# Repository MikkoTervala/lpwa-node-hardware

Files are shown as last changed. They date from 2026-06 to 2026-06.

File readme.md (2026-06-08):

# LPWA Node Hardware

Low power LTE Cat M / NB IoT cellular network temperature and humidity logger.

## Design Overview

The design is based on a combination of the ESP32-C3 and the SIMCom SIM7080G. An ESP32 family microcontroller was chosen as it offers good compatibility with ESPHome firmware generation tools, making the board more broadly usable for home automation purposes. In its intended use, the WiFi and Bluetooth functions will not be used. The purpose of the microcontroller is to gather temperature and humidity readings and transmit them to a server over a cellular connection using the SIM7080 modem.

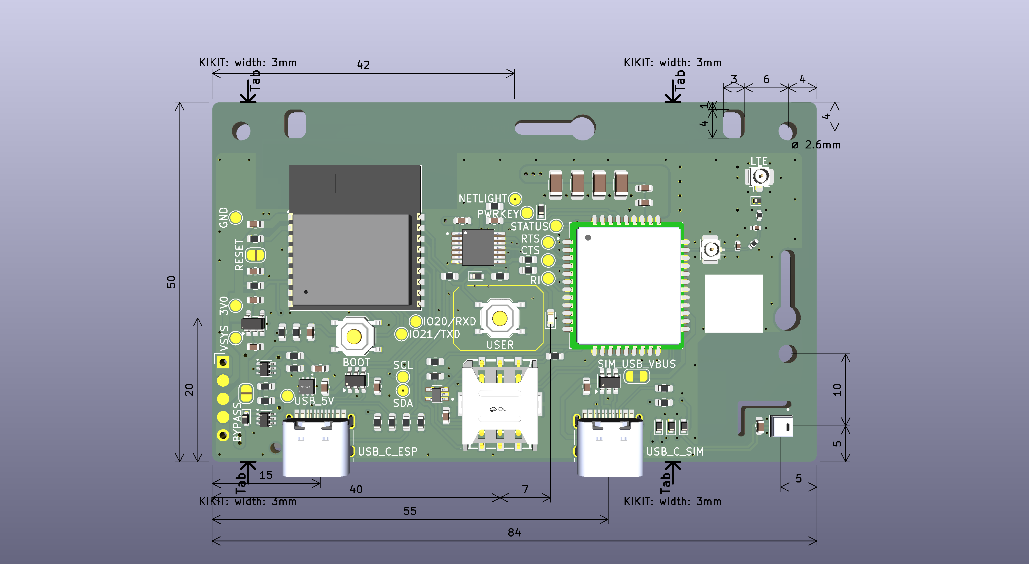
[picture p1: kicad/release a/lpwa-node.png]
LPWA Node PCB


## Views and Schematics

- [Schematic and board layout](https://kicanvas.org/?repo=https%3A%2F%2Fgithub.com%2FMikkoTervala%2Flpwa-node-hardware%2Ftree%2Fmain%2Fkicad)
- [Interactive 3D view](https://3dviewer.net/index.html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)

## Remarks

The 3.0V regulator is selected with low quiescent current as the top priority, and it cannot sustain enough current to the ESP32-C3 in WiFi operation. Replace the regulator with TLV75730PDBVR before enabling WiFi.

Maximum allowed battery voltage for the system is 4.8V. Do not use lithium 1.5V batteries as their open circuit voltage exceeds limits of this design. Stick to NiMH and alkaline.

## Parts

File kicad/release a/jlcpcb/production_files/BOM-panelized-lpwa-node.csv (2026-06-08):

Comment | Designator | Footprint | LCSC | Quantity
100k | R18,R25 | R_0603_1608Metric | C25803 | 2
100nF | C12,C14,C15,C4,C7,C8,C9 | C_0603_1608Metric | C161115 | 7
100µF | C11,C13,C22,C23 | C_1206_3216Metric | C7432784 | 4
10k | R1,R2,R21,R22,R3 | R_0603_1608Metric | C25804 | 5
10µF | C1,C10,C2,C20,C21,C3,C5,C6 | C_0603_1608Metric | C19702 | 8
1M | R20,R23,R8,R9 | R_0603_1608Metric | C22935 | 4
22R | R10,R11,R12 | R_0603_1608Metric | C23345 | 3
5.1k | R13,R14,R4,R5,R6,R7 | R_0603_1608Metric | C23186 | 6
732k | R19,R24 | R_0603_1608Metric | C23239 | 2
AHT20 | U4 | AHT20 | C3012622 | 1
BH-AA-B6AA044 | U5 | BAT-SMD_BH-AA-B6AA044 | C19184082 | 1
BOOT | SW1 | SW_Push_1P1T_XKB_TS-1187A | C480267 | 1
ESD5Z3.3T1G | D2,D4,D7,D8,D9 | D_SOD-523 | C61148 | 5
ESD5Z5.0T1G | D3 | D_SOD-523 | C82044 | 1
ESDA6V1W5 | D5 | SOT65P210X110-5N | C48677 | 1
ESP32-C3-WROOM-02 | U3 | ESP32-C3-WROOM-02 | C2934560 | 1
LED Amber BL-HJC36G-AV-TRB | D1 | LED_0603_1608Metric | C165983 | 1
LM66100DCK | U10,U11 | SOT-363_SC-70-6 | C2869734 | 2
LTE | J8 | U.FL_Hirose_U.FL-R-SMT-1_Vertical | C88374 | 1
LXES15AAA1-153 | D6 | D_SOD-882 | C7472903 | 1
R0 | R15,R16 | R_0402_1005Metric | C60485 | 2
SIM7080G | U6 | SIM7080G | C18548266 | 1
SIM_Card | J5 | SMN-304 | C266889 | 1
TLV75901PDRVR | U9 | WSON-6_L2.0-W2.0-P0.65-TL-EP | C544759 | 1
TPS7A0230PDBVR | U1 | SOT-23-5 | C3747031 | 1
TXU0204PWR | U7 | SOP65P640X120-14N | C4363888 | 1
USBLC6-2SC6 | U2,U8 | SOT-23-6 | C7519 | 2
USB_C_ESP | J1 | USB_C_Receptacle_HRO_TYPE-C-31-M-12 | C165948 | 1
USER | SW2 | SW_Push_1P1T_XKB_TS-1187A | C480267 | 1

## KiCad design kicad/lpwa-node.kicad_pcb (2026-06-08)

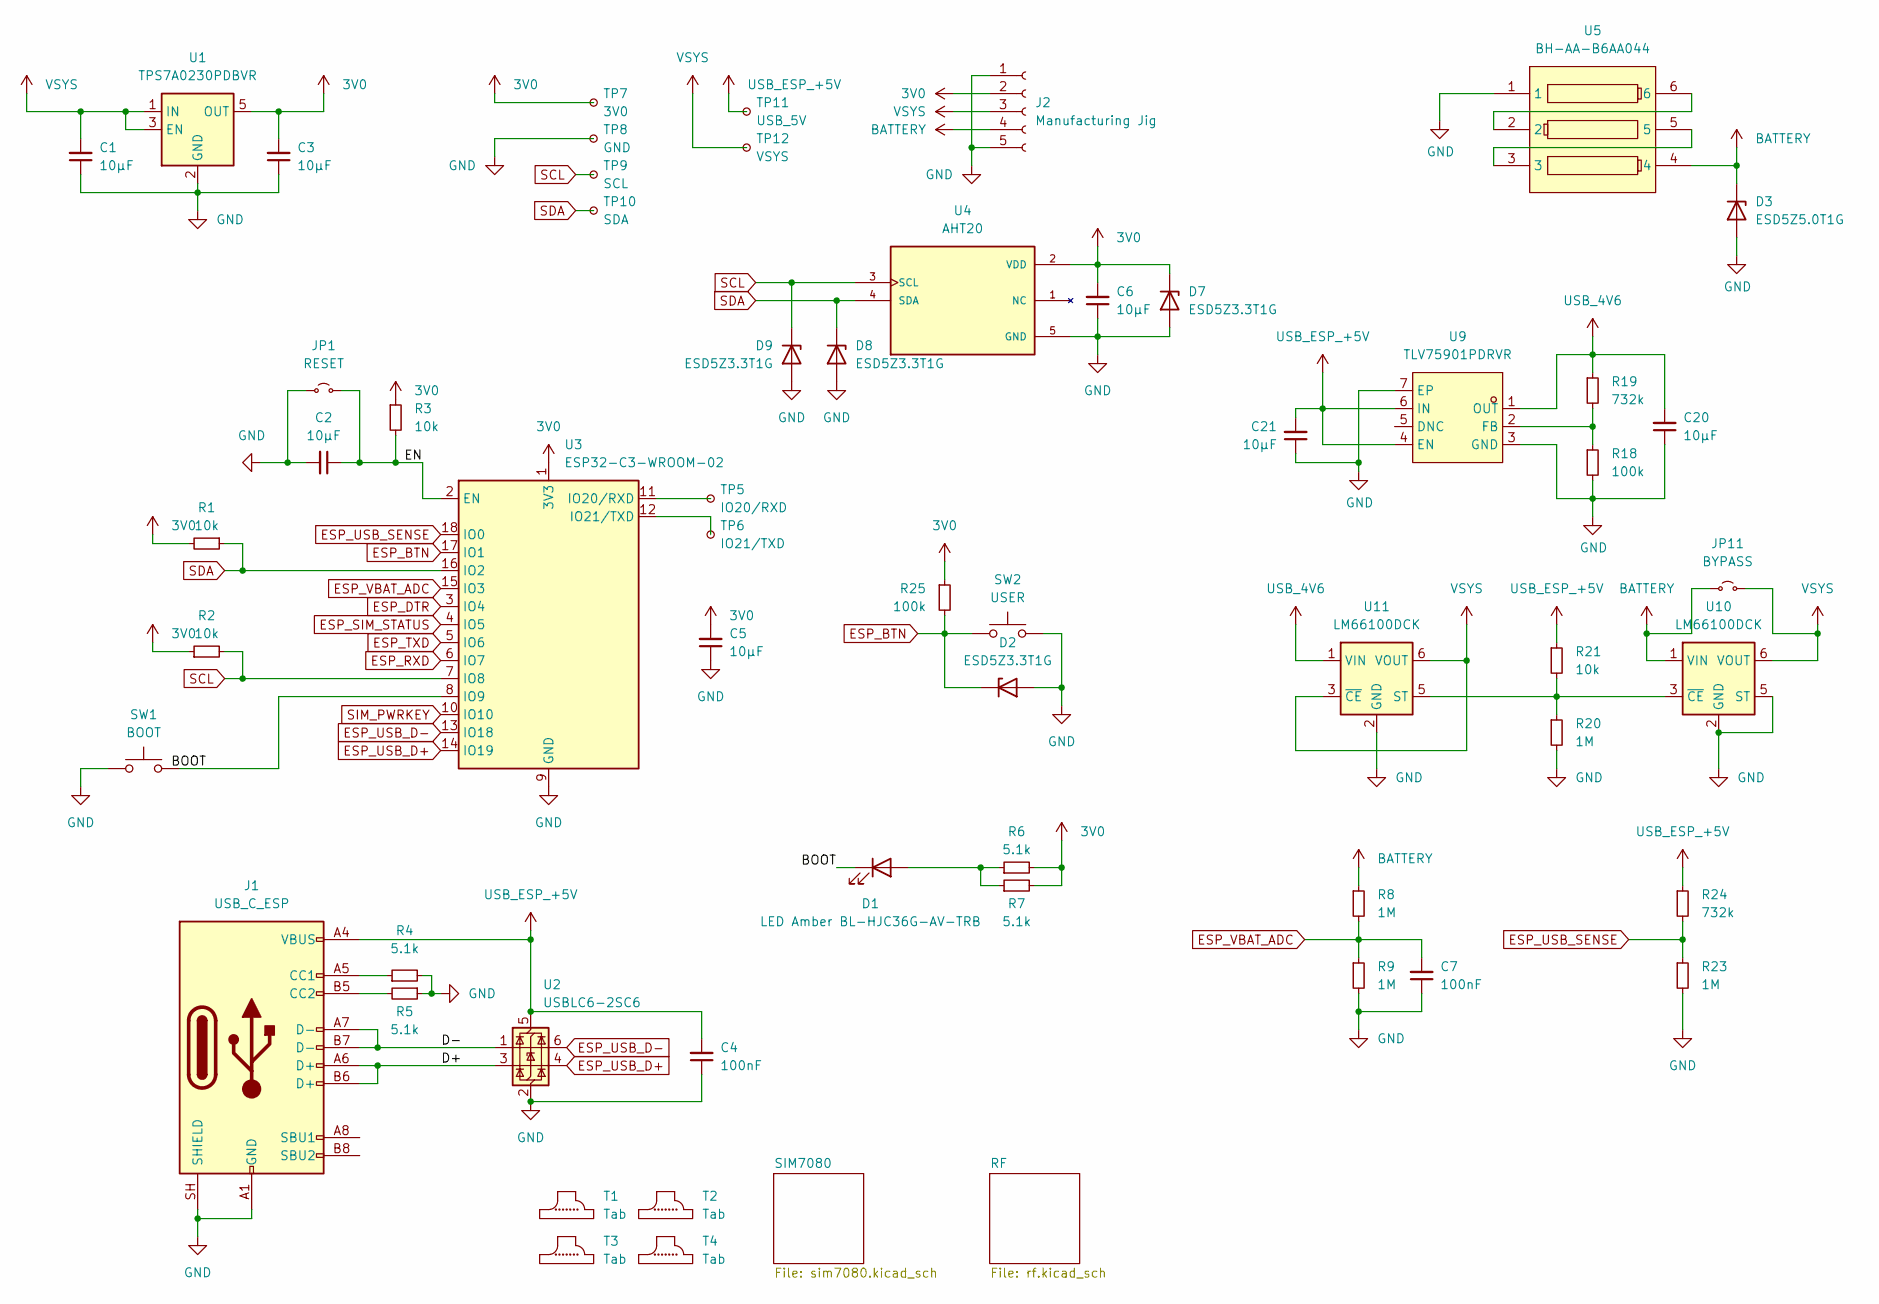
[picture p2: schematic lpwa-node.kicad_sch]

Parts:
C1, C2, C3, C5, C6, C20, C21: 10µF; C_0603_1608Metric; LCSC Part # C19702
C4, C7: 100nF; C_0603_1608Metric; LCSC Part # C161115
D1: LED Amber BL-HJC36G-AV-TRB; LED_0603_1608Metric; LCSC Part # C165983
D2, D7, D8, D9: ESD5Z3.3T1G; D_SOD-523; LCSC Part # C61148
D3: ESD5Z5.0T1G; D_SOD-523; LCSC Part # C82044
J1: USB_C_ESP; USB_C_Receptacle_HRO_TYPE-C-31-M-12; LCSC Part # C165948
J2: Manufacturing Jig; TestHeader_1x05_P2.54mm
JP1: RESET; SolderJumper-2_P1.3mm_Open_RoundedPad1.0x1.5mm
JP11: BYPASS; SolderJumper-2_P1.3mm_Open_RoundedPad1.0x1.5mm
R1, R2, R3, R21: 10k; R_0603_1608Metric; LCSC Part # C25804
R4, R5, R6, R7: 5.1k; R_0603_1608Metric; LCSC Part # C23186
R8, R9, R20, R23: 1M; R_0603_1608Metric; LCSC Part # C22935
R18, R25: 100k; R_0603_1608Metric; LCSC Part # C25803
R19, R24: 732k; R_0603_1608Metric; LCSC Part # C23239
SW1: BOOT; SW_Push_1P1T_XKB_TS-1187A; LCSC Part # C480267
SW2: USER; SW_Push_1P1T_XKB_TS-1187A; LCSC Part # C480267
T1, T2, T3, T4: Tab
TP5: IO20/RXD; TestPoint_Pad_D1.5mm
TP6: IO21/TXD; TestPoint_Pad_D1.5mm
TP7: 3V0; TestPoint_Pad_D1.5mm
TP8: GND; TestPoint_Pad_D1.5mm
TP9: SCL; TestPoint_Pad_D1.5mm
TP10: SDA; TestPoint_Pad_D1.5mm
TP11: USB_5V; TestPoint_Pad_D1.5mm
TP12: VSYS; TestPoint_Pad_D1.5mm
U1: TPS7A0230PDBVR; SOT-23-5; LCSC Part # C3747031
U2: USBLC6-2SC6; SOT-23-6; LCSC Part # C7519
U3: ESP32-C3-WROOM-02; LCSC Part # C2934560
U4: AHT20; PARTREV V1.0; LCSC Part # C3012622
U5: BH-AA-B6AA044; BAT-SMD_BH-AA-B6AA044; MPN BH-AA-B6AA044; LCSC Part # C19184082
U9: TLV75901PDRVR; WSON-6_L2.0-W2.0-P0.65-TL-EP; MPN TLV75901PDRVR; LCSC Part # C544759
U10, U11: LM66100DCK; SOT-363_SC-70-6; LCSC Part # C2869734

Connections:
3V0: C3.2, C5.2, C6.2, D7.1 (K), J2.2, R1.2, R2.1, R3.1, R6.2, R7.2, R25.1, TP7.1 (1_1), U1.5 (OUT), U3.1 (3V3), U4.2 (VDD); also elsewhere on the board
/BOOT: D1.1 (K), SW1.2, U3.8 (IO9)
/D+: J1.A6 (D+), J1.B6 (D+), U2.3 (I/O2)
/D-: J1.A7 (D-), J1.B7 (D-), U2.1 (I/O1)
/EN: C2.1, JP1.2 (B), R3.2, U3.2 (EN)
BATTERY: D3.1 (K), J2.4, JP11.1 (A), R8.1, U5.4, U10.1 (VIN)
ESP_BTN: D2.1 (K), R25.2, SW2.1, U3.17 (IO1)
ESP_DTR: U3.3 (IO4); also elsewhere on the board
ESP_RXD: U3.6 (IO7); also elsewhere on the board
ESP_SIM_STATUS: U3.4 (IO5); also elsewhere on the board
ESP_TXD: U3.5 (IO6); also elsewhere on the board
ESP_USB_D+: U2.4 (I/O2), U3.14 (IO19)
ESP_USB_D-: U2.6 (I/O1), U3.13 (IO18)
ESP_USB_SENSE: R23.1, R24.2, U3.18 (IO0)
ESP_VBAT_ADC: C7.2, R8.2, R9.1, U3.15 (IO3)
GND: C1.1, C2.2, C3.1, C4.1, C5.1, C6.1, C7.1, C20.1, C21.1, D2.2 (A), D3.2 (A), D7.2 (A), D8.2 (A), D9.2 (A), J1.A1 (GND), J1.A12 (GND), J1.B1 (GND), J1.B12 (GND), J1.SH (SHIELD), J2.1, J2.5, JP1.1 (A), R4.2, R5.1, R9.2, R18.2, R20.2, R23.2, SW1.1, SW2.2, TP8.1 (1_1), U1.2 (GND), U2.2 (GND), U3.9 (GND), U3.19 (GND), U4.5 (GND), U5.1, U9.3 (GND), U9.7 (EP), U10.2 (GND), U10.5 (ST), U11.2 (GND); also elsewhere on the board
unnamed: D1.2 (A), R6.1, R7.1
unnamed: J1.A5 (CC1), R4.1
unnamed: J1.B5 (CC2), R5.2
unnamed: TP5.1 (1_1), U3.11 (IO20/RXD)
unnamed: TP6.1 (1_1), U3.12 (IO21/TXD)
unnamed: U5.2, U5.6
unnamed: U5.3, U5.5
unnamed: R18.1, R19.2, U9.2 (FB)
unnamed: R20.1, R21.2, U10.3 (~CE), U11.5 (ST)
SCL: D9.1 (K), R2.2, TP9.1 (1_1), U3.7 (IO8), U4.3 (SCL)
SDA: D8.1 (K), R1.1, TP10.1 (1_1), U3.16 (IO2), U4.4 (SDA)
SIM_PWRKEY: U3.10 (IO10); also elsewhere on the board
USB_4V6: C20.2, R19.1, U9.1 (OUT), U11.1 (VIN)
USB_ESP_+5V: C4.2, C21.2, J1.A4 (VBUS), J1.A9 (VBUS), J1.B4 (VBUS), J1.B9 (VBUS), R21.1, R24.1, TP11.1 (1_1), U2.5 (VBUS), U9.4 (EN), U9.6 (IN)
VSYS: C1.2, J2.3, JP11.2 (B), TP12.1 (1_1), U1.1 (IN), U1.3 (EN), U10.6 (VOUT), U11.3 (~CE), U11.6 (VOUT); also elsewhere on the board

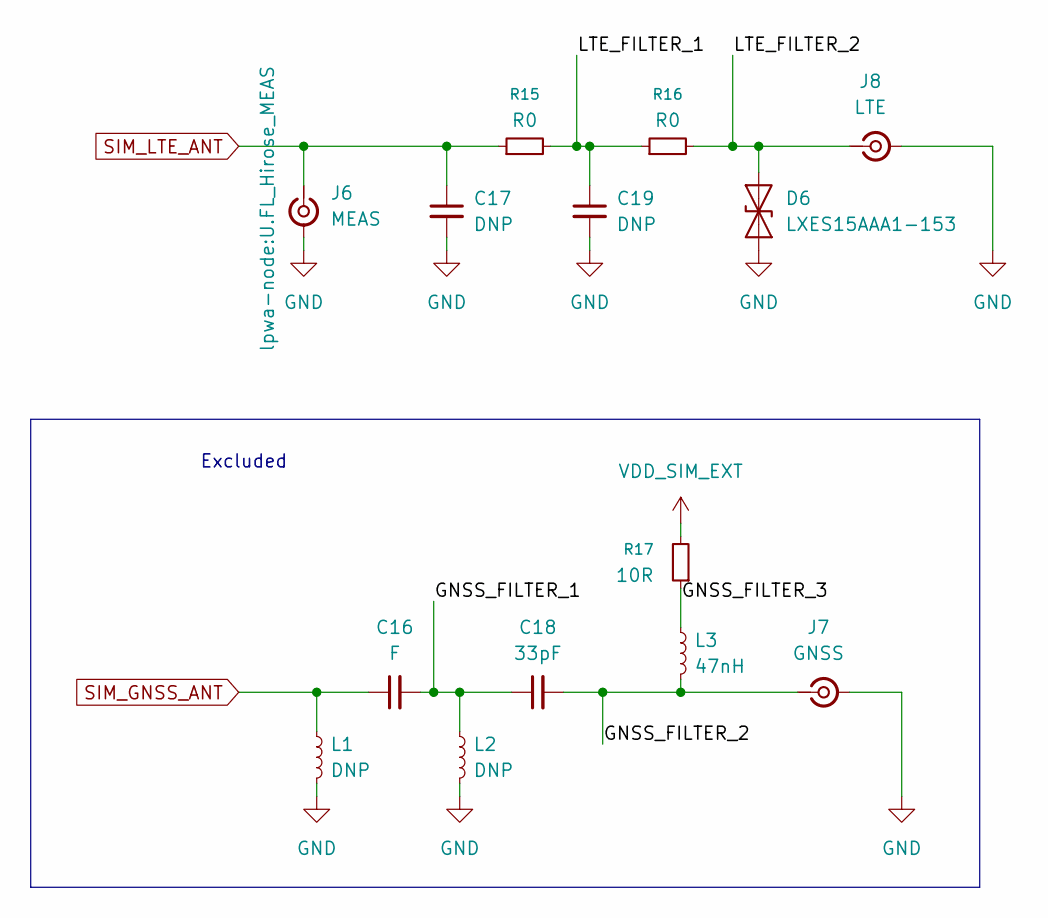
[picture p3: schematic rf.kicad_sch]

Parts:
C16: F; C_0402_1005Metric
C17, C19: DNP; C_0402_1005Metric
C18: 33pF; C_0402_1005Metric
D6: LXES15AAA1-153; D_SOD-882; LCSC Part # C7472903
J6: MEAS; U.FL_Hirose_MEAS; LCSC Part # C88374
J7: GNSS; U.FL_Hirose_U.FL-R-SMT-1_Vertical; LCSC Part # C88374
J8: LTE; U.FL_Hirose_U.FL-R-SMT-1_Vertical; LCSC Part # C88374
L1, L2: DNP; L_0402_1005Metric
L3: 47nH; L_0402_1005Metric
R15, R16: R0; R_0402_1005Metric; LCSC Part # C60485
R17: 10R; R_0402_1005Metric

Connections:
/RF/LTE_FILTER_1: C19.1, R15.2, R16.1
/RF/LTE_FILTER_2: D6.2 (A2), J8.1 (In), R16.2
GND: C17.2, C19.2, D6.1 (A1), J6.2 (Ext), J7.2 (Ext), J8.2 (Ext), L1.2, L2.2; also elsewhere on the board
unnamed: C16.1, L1.1
unnamed: C16.2, C18.1, L2.1
unnamed: C18.2, J7.1 (In), L3.2
unnamed: L3.1, R17.1
SIM_LTE_ANT: C17.1, J6.1 (In), R15.1; also elsewhere on the board

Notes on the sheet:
Excluded

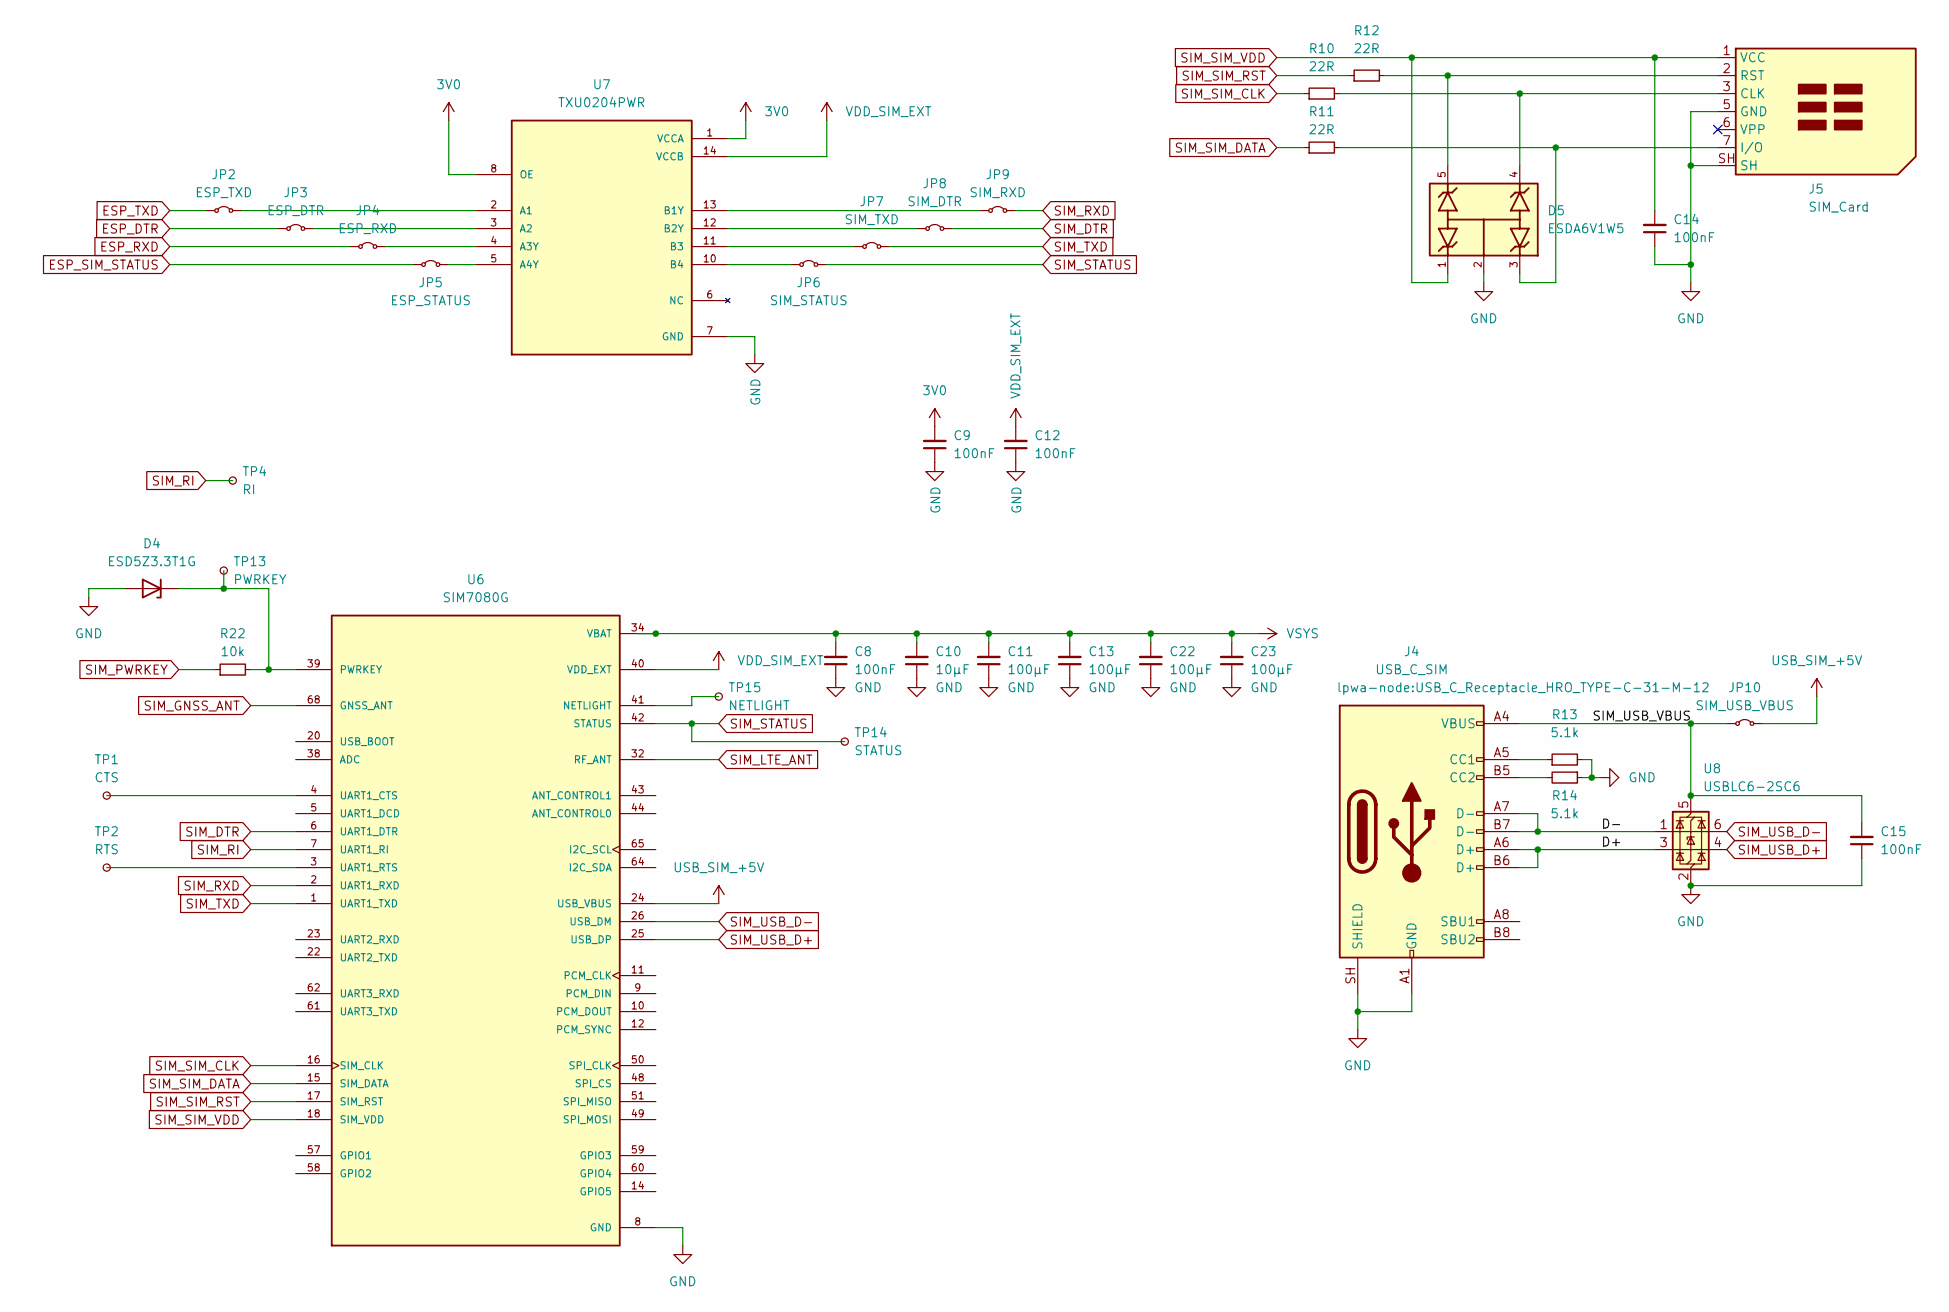
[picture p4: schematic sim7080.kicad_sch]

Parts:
C8, C9, C12, C14, C15: 100nF; C_0603_1608Metric; LCSC Part # C161115
C10: 10µF; C_0603_1608Metric; LCSC Part # C19702
C11, C13, C22, C23: 100µF; C_1206_3216Metric; LCSC Part # C7432784
D4: ESD5Z3.3T1G; D_SOD-523; LCSC Part # C61148
D5: ESDA6V1W5; SOT65P210X110-5N; PARTREV 2; LCSC Part # C48677
J4: USB_C_SIM; USB_C_Receptacle_HRO_TYPE-C-31-M-12; LCSC Part # C165948
J5: SIM_Card; SMN-304; LCSC Part # C266889
JP2: ESP_TXD; SolderJumper-2_P1.3mm_Bridged_RoundedPad1.0x1.5mm
JP3: ESP_DTR; SolderJumper-2_P1.3mm_Bridged_RoundedPad1.0x1.5mm
JP4: ESP_RXD; SolderJumper-2_P1.3mm_Bridged_RoundedPad1.0x1.5mm
JP5: ESP_STATUS; SolderJumper-2_P1.3mm_Bridged_RoundedPad1.0x1.5mm
JP6: SIM_STATUS; SolderJumper-2_P1.3mm_Bridged_RoundedPad1.0x1.5mm
JP7: SIM_TXD; SolderJumper-2_P1.3mm_Bridged_RoundedPad1.0x1.5mm
JP8: SIM_DTR; SolderJumper-2_P1.3mm_Bridged_RoundedPad1.0x1.5mm
JP9: SIM_RXD; SolderJumper-2_P1.3mm_Bridged_RoundedPad1.0x1.5mm
JP10: SIM_USB_VBUS; SolderJumper-2_P1.3mm_Bridged_RoundedPad1.0x1.5mm
R10, R11, R12: 22R; R_0603_1608Metric; LCSC Part # C23345
R13, R14: 5.1k; R_0603_1608Metric; LCSC Part # C23186
R22: 10k; R_0603_1608Metric; LCSC Part # C25804
TP1: CTS; TestPoint_Pad_D1.5mm
TP2: RTS; TestPoint_Pad_D1.5mm
TP4: RI; TestPoint_Pad_D1.5mm
TP13: PWRKEY; TestPoint_Pad_D1.5mm
TP14: STATUS; TestPoint_Pad_D1.5mm
TP15: NETLIGHT; TestPoint_Pad_D1.5mm
U6: SIM7080G; PARTREV 1.04; LCSC Part # C18548266
U7: TXU0204PWR; SOP65P640X120-14N; PARTREV A; LCSC Part # C4363888
U8: USBLC6-2SC6; SOT-23-6; LCSC Part # C7519

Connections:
3V0: C9.2, U7.1 (VCCA), U7.8 (OE); also elsewhere on the board
/SIM7080/D+: J4.A6 (D+), J4.B6 (D+), U8.3 (I/O2)
/SIM7080/D-: J4.A7 (D-), J4.B7 (D-), U8.1 (I/O1)
/SIM7080/SIM_USB_VBUS: C15.2, J4.A4 (VBUS), J4.A9 (VBUS), J4.B4 (VBUS), J4.B9 (VBUS), JP10.1 (A), U8.5 (VBUS)
ESP_DTR: JP3.1 (A); also elsewhere on the board
ESP_RXD: JP4.1 (A); also elsewhere on the board
ESP_SIM_STATUS: JP5.1 (A); also elsewhere on the board
ESP_TXD: JP2.1 (A); also elsewhere on the board
GND: C8.1, C9.1, C10.1, C11.1, C12.1, C13.1, C14.1, C15.1, C22.1, C23.1, D4.2 (A), D5.2, J4.A1 (GND), J4.A12 (GND), J4.B1 (GND), J4.B12 (GND), J4.SH (SHIELD), J5.5 (GND), J5.SH, R13.2, R14.1, U6.8 (GND), U6.13 (GND), U6.19 (GND), U6.21 (GND), U6.27 (GND), U6.30 (GND), U6.31 (GND), U6.33 (GND), U6.36 (GND), U6.37 (GND), U6.45 (GND), U6.63 (GND), U6.66 (GND), U6.67 (GND), U6.69 (GND), U6.70 (GND), U6.71 (GND), U6.72 (GND), U6.73 (GND), U6.74 (GND), U6.75 (GND), U6.76 (GND), U6.77 (GND), U7.7 (GND), U8.2 (GND); also elsewhere on the board
unnamed: D4.1 (K), R22.2, TP13.1 (1_1), U6.39 (PWRKEY)
unnamed: J4.A5 (CC1), R13.1
unnamed: J4.B5 (CC2), R14.2
unnamed: D5.4, J5.3 (CLK), R10.2
unnamed: D5.3, J5.7 (I/O), R11.2
unnamed: D5.5, J5.2 (RST), R12.2
unnamed: JP2.2 (B), U7.2 (A1)
unnamed: JP3.2 (B), U7.3 (A2)
unnamed: JP4.2 (B), U7.4 (A3Y)
unnamed: JP5.2 (B), U7.5 (A4Y)
unnamed: JP6.1 (A), U7.10 (B4)
unnamed: JP7.1 (A), U7.11 (B3)
unnamed: JP8.1 (A), U7.12 (B2Y)
unnamed: JP9.1 (A), U7.13 (B1Y)
unnamed: TP15.1 (1_1), U6.41 (NETLIGHT)
unnamed: TP1.1 (1_1), U6.4 (UART1_CTS)
unnamed: TP2.1 (1_1), U6.3 (UART1_RTS)
SIM_DTR: JP8.2 (B), U6.6 (UART1_DTR)
SIM_GNSS_ANT: U6.68 (GNSS_ANT)
SIM_LTE_ANT: U6.32 (RF_ANT); also elsewhere on the board
SIM_PWRKEY: R22.1; also elsewhere on the board
SIM_RI: TP4.1 (1_1), U6.7 (UART1_RI)
SIM_RXD: JP9.2 (B), U6.2 (UART1_RXD)
SIM_SIM_CLK: R10.1, U6.16 (SIM_CLK)
SIM_SIM_DATA: R11.1, U6.15 (SIM_DATA)
SIM_SIM_RST: R12.1, U6.17 (SIM_RST)
SIM_SIM_VDD: C14.2, D5.1, J5.1 (VCC), U6.18 (SIM_VDD)
SIM_STATUS: JP6.2 (B), TP14.1 (1_1), U6.42 (STATUS)
SIM_TXD: JP7.2 (B), U6.1 (UART1_TXD)
SIM_USB_D+: U6.25 (USB_DP), U8.4 (I/O2)
SIM_USB_D-: U6.26 (USB_DM), U8.6 (I/O1)
USB_SIM_+5V: JP10.2 (B), U6.24 (USB_VBUS)
VDD_SIM_EXT: C12.2, U6.40 (VDD_EXT), U7.14 (VCCB)
VSYS: C8.2, C10.2, C11.2, C13.2, C22.2, C23.2, U6.34 (VBAT), U6.35 (VBAT); also elsewhere on the board

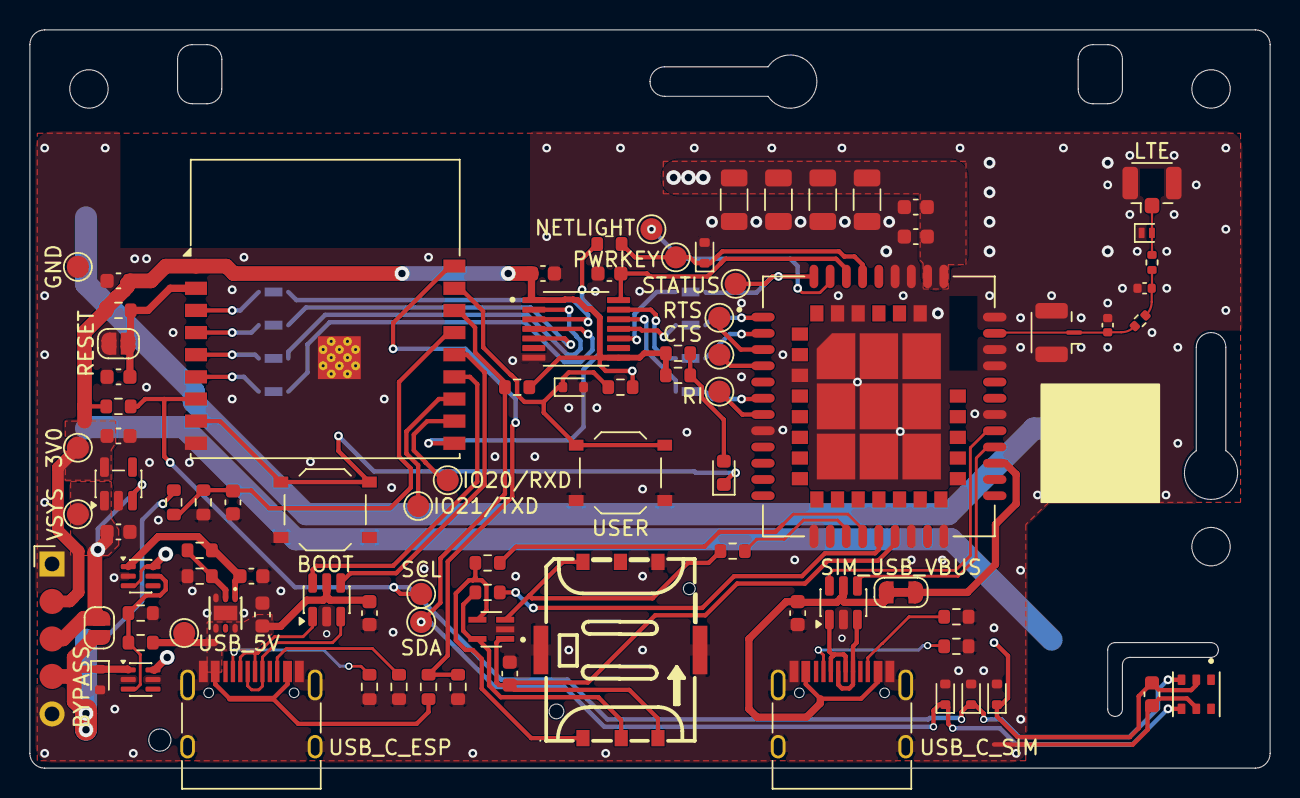
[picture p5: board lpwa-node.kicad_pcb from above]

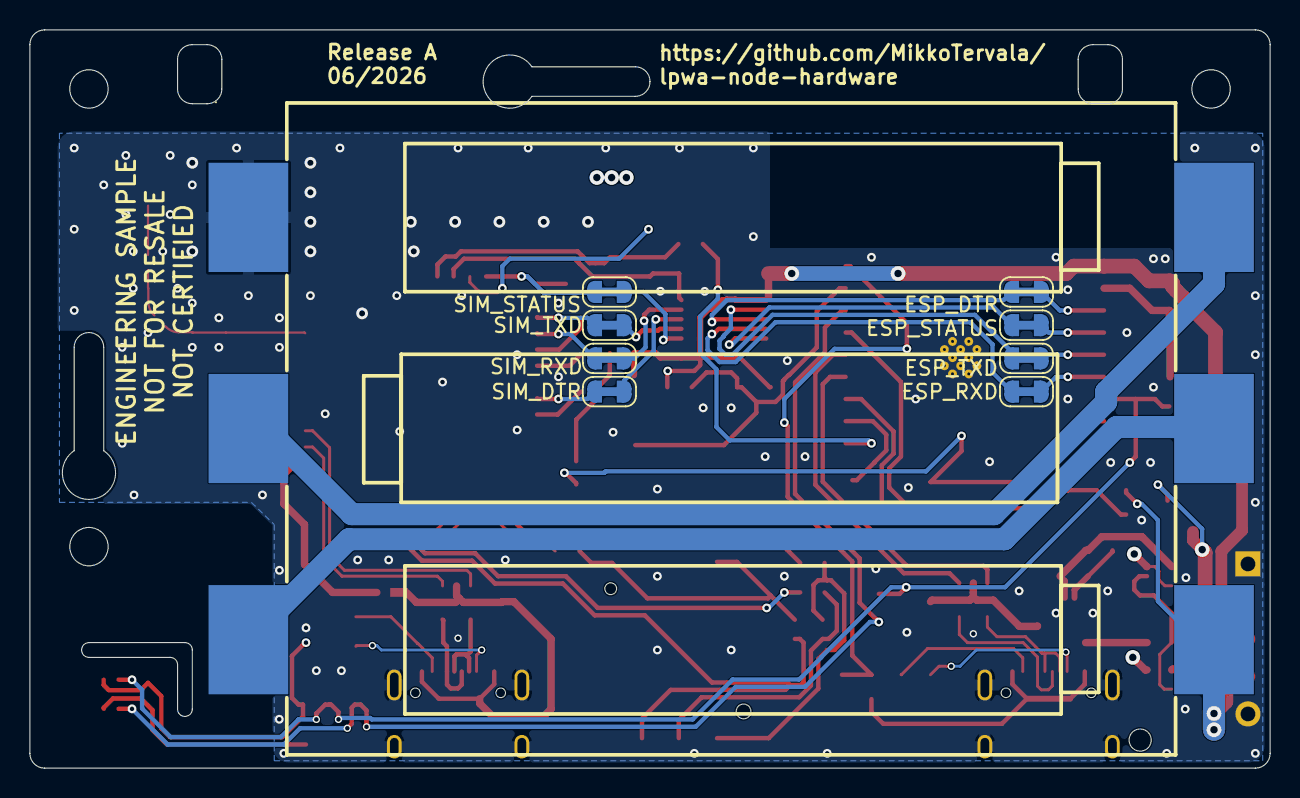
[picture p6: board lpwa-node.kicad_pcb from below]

Board: 4 copper layers, 84.0 x 50.0 mm, 102 parts (9 on the bottom side), 67 nets.

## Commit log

2026-06-01 Add component symbols and footprints
2026-06-05 Remove copper from mechanical holes
2026-06-05 First orderable version
    [lpwa-node.kicad_pcb, lpwa-node.kicad_sch, sim7080.kicad_sch]
2026-06-07 Optimize for manufacturing, add part numbers
    [lpwa-node.kicad_pcb, lpwa-node.kicad_sch, rf.kicad_sch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]
2026-06-08 Release A
    [BOM-panelized-lpwa-node.csv, lpwa-node.kicad_pcb, lpwa-node.kicad_sch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]
